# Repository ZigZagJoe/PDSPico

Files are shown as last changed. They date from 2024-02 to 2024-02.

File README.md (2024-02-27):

# PDSPico

early days of a project to interface a Pico W microcontroller to a 68030 bus
hardware has been validated, code WIP

## modes of access.

### PICO starts at 0xfX000000

16 bit port, 4 address bits A8-A11

intended for use as FIFOs between Pico and 68030 for bulk data transfer
anticipated to be accelerated by PIOs

### Status  at     0xfX400000

8 bit port, no address bits. 

automatically dsack by GAL. intent is to allow the pico to leave status flags on its bus and the 68030 can poll without needing to interrupt pico

### ROM starts at  0xfXc00000

8 bit port, 12 address bits A0-A11 (4KB)

intended to provide DeclROM emulation, but as this will also be writable it can be used for ancillary data transfer/registers
expected to be slower as pico CPU will need to be interrupted to handle these accesses.

X is slot, A or B selectable

## IO resources:

- USB-A host port connected to pico's USB port: possibility for mass storage or other fun things
- Wifi on the Pico module
- One free output on the GAL
- No free IO on the Pico. One output used for two LEDs: could be repurposed.
- The upper section of the multiplexed data bus could possibly be used for shared IO, but this would require blocking of the host's access to anything but status bits....

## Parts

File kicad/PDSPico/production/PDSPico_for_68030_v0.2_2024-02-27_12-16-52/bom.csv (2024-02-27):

Designator | Footprint | Quantity | Value | LCSC Part #
C1, C14, C15, C2, C4 | 0805 | 5 | 22uF | C45783
C3, C6, C7, C8, C9 | 0805 | 5 | 220nf | C5378
CN1 | 650949-5 RA MALE | 1 | PDS_LB_MALE | C3652939
D1 | D_SOD-323_HandSoldering | 1 | D_Schottky | C191023
D2 | 0805 | 1 | RED | C84256
D3 | 0805 | 1 | GRN | C2297
F1 | 1210 | 1 | 1.1A 6V | C2649912
J2 | USB_A_Horizontal_Generic | 1 | USB_A | C720525
JP1 | PinHeader_1x02_P2.54mm_Vertical | 1 | SLOT | N/A
R1 | 0805 | 1 | 1K | C17513
R10, R11, R12, R13, R14, R15, R16, R17, R18, R21, R22, R23, R24, R3, R4, R5, R6, R7, R8, R9 | 0805 | 20 | 200 | C17540
R19, R2, R20 | 0805 | 3 | 4.7K | C17673
TP1 | TestPoint-2 RRect 1.5mmX2mm | 1 | USB_DATA | N/A
U1, U4 | SOIC-20W_7.5x12.8mm_P1.27mm | 2 | 74LV*245 | C571201
U2 | SOT-223-3_TabPin2 | 1 | 1117-3.3 | C6186
U3 | RPi_Pico_SMD | 1 | RPI Pico W | N/A
U5 | DIP-24_W7.62mm_Socket | 1 | ATF22V10 | C146581
U6, U7 | SOIC-20W_7.5x12.8mm_P1.27mm | 2 | 74LV*541 | C2652110

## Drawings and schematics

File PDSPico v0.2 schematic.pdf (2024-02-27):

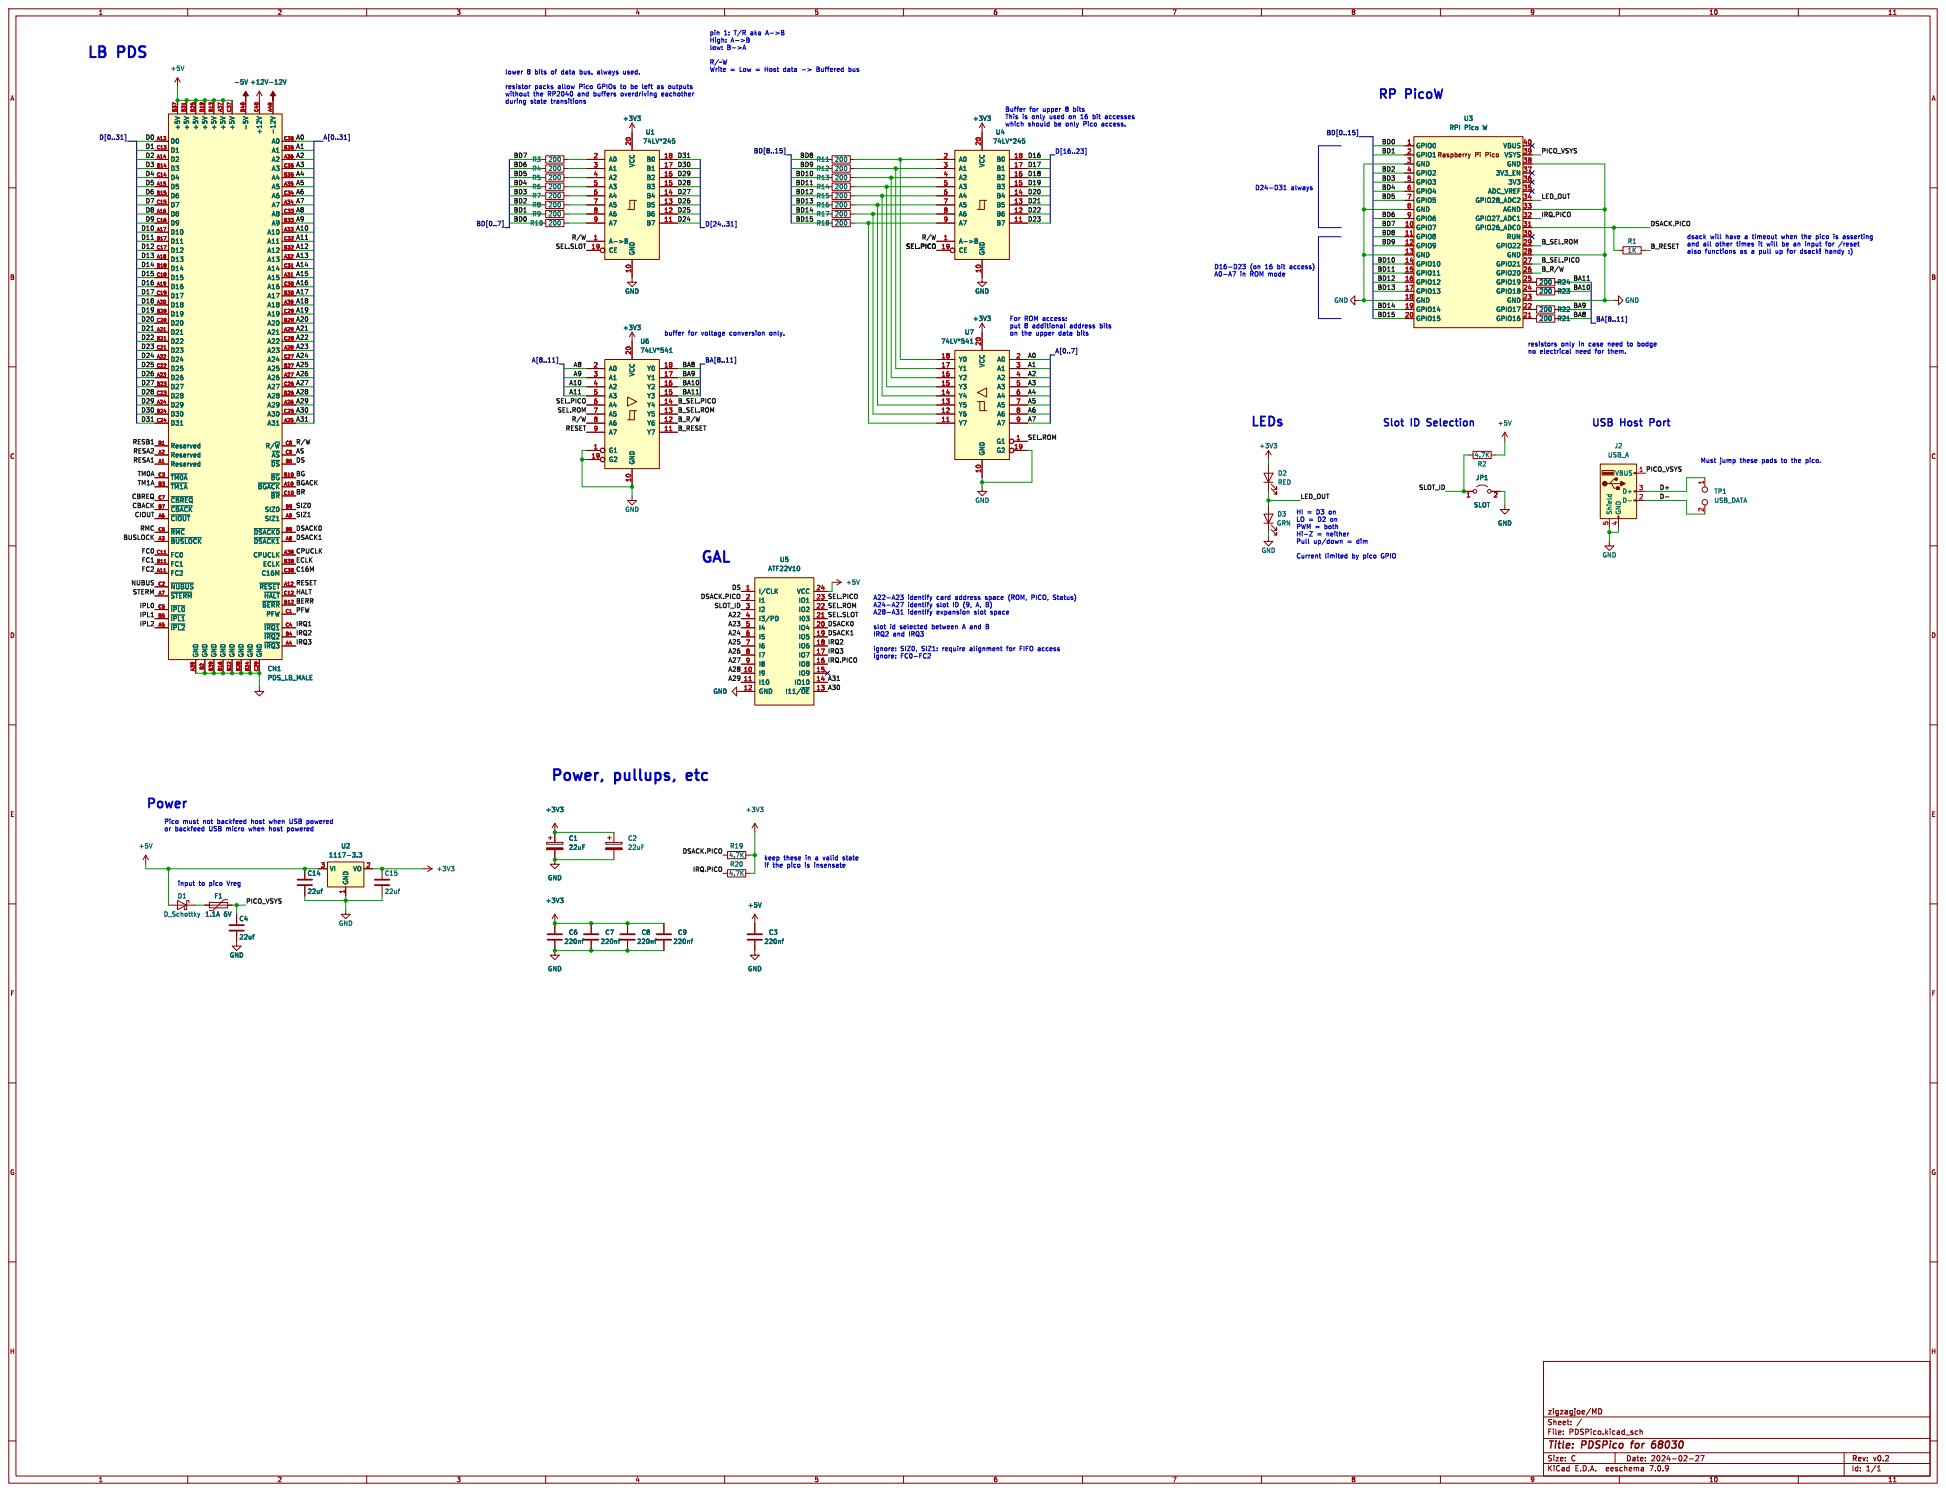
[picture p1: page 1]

Must jump these pads to the pico.

Current limited by pico GPIO

ignore: FC0-FC2 Power, pullups, etc

Pico must not backfeed host when USB powered
or backfeed USB micro when host powered

keep these in a valid state

input to pico Vreg

File: PDSPico.kicad_sch Sheet: / zigzagjoe/MD

Id: 1/1 Title: PDSPico for 68030

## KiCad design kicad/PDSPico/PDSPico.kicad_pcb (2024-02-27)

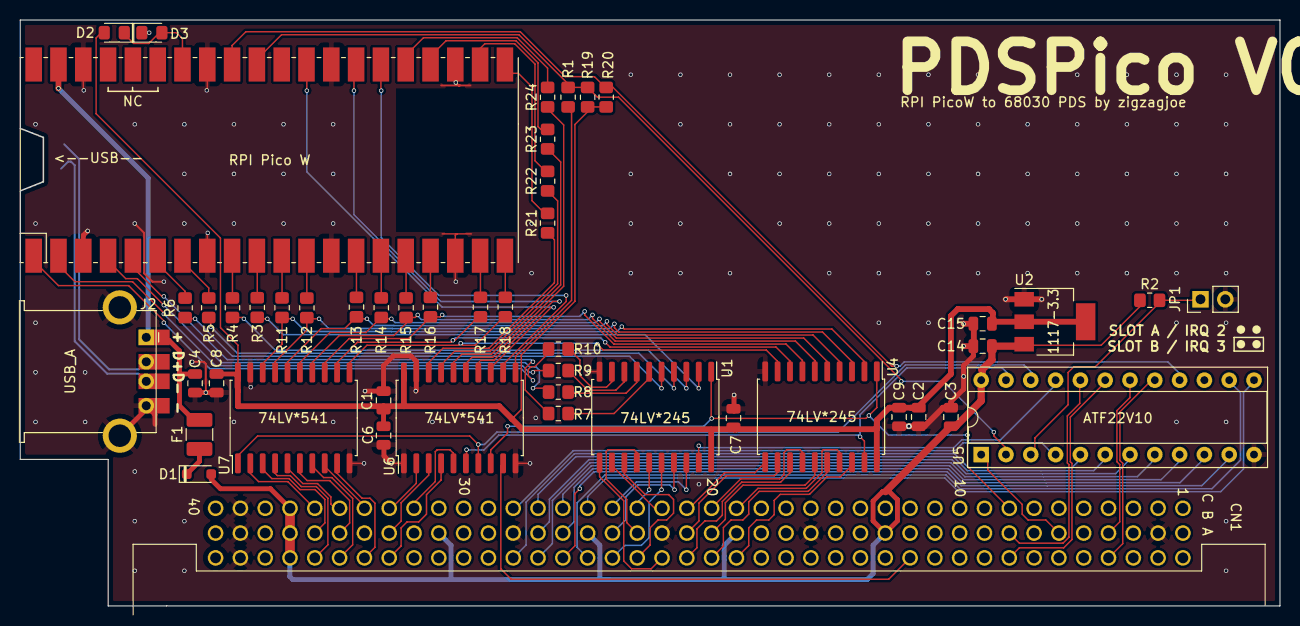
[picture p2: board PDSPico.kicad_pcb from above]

Board: 2 copper layers, 129.0 x 60.0 mm, 49 parts (1 on the bottom side), 103 nets.

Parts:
C1, C2: 22uF; C_0805_2012Metric
C3, C6, C7, C8, C9: 220nf; C_0805_2012Metric
C4, C14, C15: 22uf; C_0805_2012Metric
CN1: PDS_LB_MALE; 650949-5 RA MALE
D1: D_Schottky; D_SOD-323_HandSoldering
D2: RED; LED_0805_2012Metric_Pad1.15x1.40mm_HandSolder
D3: GRN; LED_0805_2012Metric_Pad1.15x1.40mm_HandSolder
F1: 1.1A 6V; Fuse_1210_3225Metric_Pad1.42x2.65mm_HandSolder
J2: USB_A; USB_A_Horizontal_Generic
JP1: SLOT; PinHeader_1x02_P2.54mm_Vertical
R1: 1K; R_0805_2012Metric_Pad1.20x1.40mm_HandSolder
R2, R19, R20: 4.7K; R_0805_2012Metric_Pad1.20x1.40mm_HandSolder
R3, R4, R5, R6, R7, R8, R9, R10, R11, R12, R13, R14, R15, R16, R17, R18, R21, R22, R23, R24: 200; R_0805_2012Metric_Pad1.20x1.40mm_HandSolder
TP1: USB_DATA; TestPoint-2 RRect 1.5mmX2mm
U1, U4: 74LV*245; SOIC-20W_7.5x12.8mm_P1.27mm
U2: 1117-3.3; SOT-223-3_TabPin2
U3: RPI Pico W; RPi_Pico_SMD
U5: ATF22V10; DIP-24_W7.62mm_Socket
U6, U7: 74LV*541; SOIC-20W_7.5x12.8mm_P1.27mm

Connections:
+3V3: C1.1, C2.1, C6.1, C7.1, C8.1, C9.1, C15.1, D2.2 (A), R19.2, R20.1, U1.20 (VCC), U2.2 (VO), U4.20 (VCC), U6.20 (VCC), U7.20 (VCC)
+5V: C3.1, C14.1, CN1.A37 (+5V), CN1.B13 (+5V), CN1.B19 (+5V), CN1.B25 (+5V), CN1.B31 (+5V), CN1.B37 (+5V), CN1.C37 (+5V), D1.2 (A), R2.1, U2.3 (VI), U5.24 (VCC)
/A0: CN1.C36 (A0), U7.2 (A0)
/A1: CN1.B36 (A1), U7.3 (A1)
/A2: CN1.A36 (A2), U7.4 (A2)
/A3: CN1.C35 (A3), U7.5 (A3)
/A4: CN1.B35 (A4), U7.6 (A4)
/A5: CN1.A35 (A5), U7.7 (A5)
/A6: CN1.C34 (A6), U7.8 (A6)
/A7: CN1.A34 (A7), U7.9 (A7)
/A8: CN1.C33 (A8), U6.2 (A0)
/A9: CN1.B33 (A9), U6.3 (A1)
/A10: CN1.A33 (A10), U6.4 (A2)
/A11: CN1.C32 (A11), U6.5 (A3)
/A22: CN1.C28 (A22), U5.4 (I3/PD)
/A23: CN1.A28 (A23), U5.5 (I4)
/A24: CN1.C27 (A24), U5.6 (I5)
/A25: CN1.B27 (A25), U5.7 (I6)
/A26: CN1.A27 (A26), U5.8 (I7)
/A27: CN1.C26 (A27), U5.9 (I8)
/A28: CN1.B26 (A28), U5.10 (I9)
/A29: CN1.A26 (A29), U5.11 (I10)
/A30: CN1.C25 (A30), U5.13 (I11/~OE)
/A31: CN1.A25 (A31), U5.14 (IO10)
/BA8: R21.1, U6.18 (Y0)
/BA9: R22.1, U6.17 (Y1)
/BA10: R23.1, U6.16 (Y2)
/BA11: R24.1, U6.15 (Y3)
/BD0: R10.1, U3.1 (GPIO0)
/BD1: R9.1, U3.2 (GPIO1)
/BD2: R8.1, U3.4 (GPIO2)
/BD3: R7.1, U3.5 (GPIO3)
/BD4: R6.1, U3.6 (GPIO4)
/BD5: R5.1, U3.7 (GPIO5)
/BD6: R4.1, U3.9 (GPIO6)
/BD7: R3.1, U3.10 (GPIO7)
/BD8: R11.1, U3.11 (GPIO8)
/BD9: R12.1, U3.12 (GPIO9)
/BD10: R13.1, U3.14 (GPIO10)
/BD11: R14.1, U3.15 (GPIO11)
/BD12: R15.1, U3.16 (GPIO12)
/BD13: R16.1, U3.17 (GPIO13)
/BD14: R17.1, U3.19 (GPIO14)
/BD15: R18.1, U3.20 (GPIO15)
/B_RESET: R1.2, U6.11 (Y7)
/B_R/W: U3.26 (GPIO20), U6.12 (Y6)
/B_SEL.PICO: U3.27 (GPIO21), U6.14 (Y4)
/B_SEL.ROM: U3.29 (GPIO22), U6.13 (Y5)
/D16: CN1.A19 (D16), U4.18 (B0)
/D17: CN1.C19 (D17), U4.17 (B1)
/D18: CN1.A20 (D18), U4.16 (B2)
/D19: CN1.B20 (D19), U4.15 (B3)
/D20: CN1.C20 (D20), U4.14 (B4)
/D21: CN1.A21 (D21), U4.13 (B5)
/D22: CN1.B21 (D22), U4.12 (B6)
/D23: CN1.C21 (D23), U4.11 (B7)
/D24: CN1.A22 (D24), U1.11 (B7)
/D25: CN1.C22 (D25), U1.12 (B6)
/D26: CN1.A23 (D26), U1.13 (B5)
/D27: CN1.B23 (D27), U1.14 (B4)
/D28: CN1.C23 (D28), U1.15 (B3)
/D29: CN1.A24 (D29), U1.16 (B2)
/D30: CN1.B24 (D30), U1.17 (B1)
/D31: CN1.C24 (D31), U1.18 (B0)
/D+: J2.3 (D+), TP1.1
/D-: J2.2 (D-), TP1.2
/DS: CN1.B6 (~DS), U5.1 (I/CLK)
/DSACK0: CN1.B8 (~DSACK0), U5.20 (IO4)
/DSACK1: CN1.A8 (~DSACK1), U5.19 (IO5)
/DSACK.PICO: R1.1, R19.1, U3.31 (GPIO26_ADC0), U5.2 (I1)
/IRQ2: CN1.B4 (~IRQ2), U5.18 (IO6)
/IRQ3: CN1.A4 (~IRQ3), U5.17 (IO7)
/IRQ.PICO: R20.2, U3.32 (GPIO27_ADC1), U5.16 (IO8)
/LED_OUT: D2.1 (K), D3.2 (A), U3.34 (GPIO28_ADC2)
/PICO_VSYS: C4.1, F1.2, J2.1 (VBUS), U3.39 (VSYS)
/RESET: CN1.A12 (~RESET), U6.9 (A7)
/R/W: CN1.C8 (R/~W), U1.1 (A->B), U4.1 (A->B), U6.8 (A6)
/SEL.PICO: U4.19 (CE), U5.23 (IO1), U6.6 (A4)
/SEL.ROM: U5.22 (IO2), U6.7 (A5), U7.1 (G1)
/SEL.SLOT: U1.19 (CE), U5.21 (I03)
/SLOT_ID: JP1.1 (A), R2.2, U5.3 (I2)
GND: C1.2, C2.2, C3.2, C4.2, C6.2, C7.2, C8.2, C9.2, C14.2, C15.2, CN1.A39 (GND), CN1.B2 (GND), CN1.B16 (GND), CN1.B22 (GND), CN1.B28 (GND), CN1.B34 (GND), CN1.B39 (GND), CN1.C39 (GND), D3.1 (K), J2.4 (GND), J2.5 (Shield), JP1.2 (B), U1.10 (GND), U2.1 (GND), U3.3 (GND), U3.8 (GND), U3.13 (GND), U3.18 (GND), U3.23 (GND), U3.28 (GND), U3.33 (AGND), U3.38 (GND), U4.10 (GND), U5.12 (GND), U6.1 (G1), U6.10 (GND), U6.19 (G2), U7.10 (GND), U7.19 (G2)
unnamed: D1.1 (K), F1.1
unnamed: R3.2, U1.2 (A0)
unnamed: R4.2, U1.3 (A1)
unnamed: R5.2, U1.4 (A2)
unnamed: R6.2, U1.5 (A3)
unnamed: R7.2, U1.6 (A4)
unnamed: R8.2, U1.7 (A5)
unnamed: R9.2, U1.8 (A6)
unnamed: R10.2, U1.9 (A7)
unnamed: R21.2, U3.21 (GPIO16)
unnamed: R22.2, U3.22 (GPIO17)
unnamed: R23.2, U3.24 (GPIO18)
unnamed: R24.2, U3.25 (GPIO19)
unnamed: R11.2, U4.2 (A0), U7.18 (Y0)
unnamed: R12.2, U4.3 (A1), U7.17 (Y1)
unnamed: R13.2, U4.4 (A2), U7.16 (Y2)
unnamed: R14.2, U4.5 (A3), U7.15 (Y3)
unnamed: R15.2, U4.6 (A4), U7.14 (Y4)
unnamed: R16.2, U4.7 (A5), U7.13 (Y5)
unnamed: R17.2, U4.8 (A6), U7.12 (Y6)
unnamed: R18.2, U4.9 (A7), U7.11 (Y7)

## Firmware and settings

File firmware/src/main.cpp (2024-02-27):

#include <Arduino.h>
#include <device/usbd.h>

#include "util.h"
#include "gpio.h"

void setup() {
	board_gpio_init();

	util_init();

	led_set(GREEN_DIM);
}

void setup1() {
	delay(100);
	dbg_printf("Core 1 start\n");
}

volatile struct {
	uint16_t romAddr;
	uint8_t romData;
	uint8_t fifoAddr;
	uint16_t fifoData;
	uint32_t fifoCount;
	uint32_t romCount;
	uint8_t direction;
} lastState;

	
//, 0x
uint8_t ROM_Data[4096] = { 0xDE, 0xAD, 0xBE, 0xEF, 0xBA, 0xAD, 0xF0, 0x0D, 0xFE, 0xED, 0xFA, 0xCE, 0xCA,0xFE,0xBA,0xBE };

void loop1() {

	memset((void *)&lastState,0,sizeof(lastState));
	lastState.romData = 0x79;
	lastState.fifoData = 0xADDE;

	cli();

	data_out();
	data_write(lastState.romData);

	while(1) {
		uint32_t state = gpio_get_all();
		if (!(state & bv(SEL_PICO))) {
			lastState.fifoAddr = (state & ADDR_BUS_A8_MASK) >> 16;

			if (!(state & bv(READ_WRITE))) {
				data_in();
				busy_wait_at_least_cycles(2);
				lastState.fifoData = data_read();
				lastState.direction = 0;
			} else {
				data_write(lastState.fifoData); // must swap bytes for 16 bit IO ie 0xDEAD becomes 0xADDE
				lastState.direction = 1;
			}

			gpio_put(DSACK_PICO,0);
			busy_wait_at_least_cycles(10);
			gpio_put(DSACK_PICO,1);
			
			data_out();
			data_write(lastState.romData);

			led_set(GREEN);
			lastState.fifoCount++;

		} else if (! (state & bv(SEL_ROM))) {
			gpio_set_dir_masked(ADDR_BUS_A0_MASK,0); // set BD8-15 as inputs
			busy_wait_at_least_cycles(2); // small delay required before reading address bits. 1 or more seesm to work
			lastState.romAddr = (gpio_get_all() & ADDR_BUS_A0_FULLMASK) >> 8;
				
			if (!(state & bv(READ_WRITE))) {
				data_in();
				busy_wait_at_least_cycles(2);
				lastState.romData = data_read() & 0xFF;
				ROM_Data[lastState.romAddr] = lastState.romData;
				lastState.direction = 0;
			} else {
				data_write(ROM_Data[lastState.romAddr]);
				lastState.direction = 1;
			}
			
			gpio_put(DSACK_PICO,0);
			busy_wait_at_least_cycles(10);
			gpio_put(DSACK_PICO,1);
			
			data_out();
			data_write(lastState.romData);

			led_set(RED);
			lastState.romCount++;
		}
	}
}

/* main loop. most code runs from tinyusb task rather than here. */
void loop() {

	uint32_t lfc = 0, lrc = 0;

	while(1) {
		// platformio device monitor is dumb, and will purge any pending serial lines.
		// wait a moment before starting to dump serial logs out... as I am lazy.
		if (millis() > 3000) 
			dbg_flush_log();

		// serial bridge / command interface
		//poll_serial();

		if (lrc != lastState.romCount) {
			lrc = lastState.romCount;
			dbg_printf("rom count %d\n%c ($%x) = $%x\n",lastState.romCount,lastState.direction?'R':'W',lastState.romAddr,lastState.romData);	
		}

		if (lfc != lastState.fifoCount) {
			lfc = lastState.fifoCount;
			dbg_printf("fifo count %d\n%c ($%d) = $%x\n",lastState.fifoCount,lastState.direction?'R':'W',lastState.fifoAddr,lastState.fifoData);	
		}
	}
}

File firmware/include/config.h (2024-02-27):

/* file for compile time configurable constants */
#ifndef CONFIG_H
#define CONFIG_H

#include "version.h"

#define PRODUCT_NAME                "PDSPico"
// max 8 chars, it is used as USB VID
#define PRODUCT_VENDOR              "ZZJ"
#define PRODUCT_VERSION             VERSION_SHORT

/** SERIAL PARAMETERS ********************************************/

// serial logging and logfile shared buffer
#define SERIAL_BUFF_SZ              4096

#define SERIAL_MAX_LINE_LEN         256
#define SERIAL_MAX_TIMESTAMP_LEN    20

// delay in ms after escape sequence
#define SERIAL_CMD_BACKOFF          500
#define SERIAL_DEFAULT_BAUD         9600
#define SERIAL_BAUD_MAX             1000000

/** FLASH PARAMETERS ********************************************/

#define FLASH_BANKS                 (2)

/* flash bank size in words */
#define FLASH_BANK_WORDS            (4 * 1024 * 1024)

/* flash bank size in bytes */
#define FLASH_BANK_BYTES            (FLASH_BANK_WORDS * 2)

#define FLASH_SIZE_WORDS            (FLASH_BANKS * FLASH_BANK_WORDS)
#define FLASH_SIZE_BYTES            (FLASH_BANKS * FLASH_BANK_BYTES)

// number of sectors. require uniform sector ROM (do not support boot sector ROM)
#define FLASH_SECTORS               128

// size of flash chip's write buffer
#define FLASH_BLOCKSIZE             256

// roughly map to flash cycle time (X*7.5ns at 133mhz)
#define FLASH_DELAY_CYCLES          9

/** UF2 PARAMETERS *********************************************/

#define BOARD_UF2_FAMILY_ID         0x10C68030

#define UF2_VOLUME_LABEL            PRODUCT_NAME

// flash bytes per UF2 file
#define CFG_UF2_FLASH_SIZE          FLASH_BANK_BYTES

// Number of 512-byte blocks in the exposed filesystem, 0x10109 is just under 32MB and works with CFG_UF2_SECTORS_PER_CLUSTER = 1
// The filesystem needs space for the current file, text files, uploaded file, and FAT
#define CFG_UF2_NUM_BLOCKS          (0x10109 * 2)

// Sectors per FAT cluster, must be increased proportionally for larger filesystems
#define CFG_UF2_SECTORS_PER_CLUSTER (4)

// timeout after which the current operation is aborted
#define WATCHDOG_TIMEOUT            5000

// small grace period after writes finish before ejecting USB storage
// required so host doesn't fail the copy transfer
#define MSC_RESET_TIMEOUT           1000

#endif

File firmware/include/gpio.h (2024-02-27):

#ifndef _GPIO_H_
#define _GPIO_H_

#include <hardware/gpio.h>
#include "util.h"

/* PIN DEFINITIONS *****************************************/
// data bus, 16 bits wide
#define DATA_BUS_D0		0
#define DATA_BUS_WIDTH	16
#define DATA_BUS_MASK 	0xFFFF // 16 bits

#define ADDR_BUS_A0		8
#define ADDR_BUS_A0_MASK 	    0x0FF00 // 8 bits
#define ADDR_BUS_A0_FULLMASK 	0xFFF00 // 12 bits

/* BA8-BA11 */
#define ADDR_BUS_A8		16
#define ADDR_BUS_WIDTH	4
#define ADDR_BUS_A8_MASK 	    0xF0000 // 4 bits


#define SEL_ROM		22
#define SEL_PICO		21

#define READ_WRITE		20

#define DSACK_PICO		26
#define RESET_IN		26

#define IRQ_PICO		27

/* LED output
 hi-Z = off
	1 = green
	0 = red
	pull up/down for dim colors
*/
#define LED_OUT			28

// detect vbus present
#define VBUS_SENSE		24

/* misc defines *******************************************/

/* LED states for set_led */
enum LED_STATE { GREEN, GREEN_DIM, BOTH, RED, RED_DIM, OFF };

/* prototypes *********************************************/

#ifdef __cplusplus
extern "C" {
#endif

extern enum LED_STATE last_led_state;

/* set pin to GPIO mode, with direction and initial state */
void init_gpio_pin(uint gpio, bool dir, bool state);

/* board GPIO setup */
void board_gpio_init();

/* set LED state */
void led_set(enum LED_STATE s);

/* static inline IO functions for speed */
static inline void data_out() { 
	gpio_set_dir_masked(DATA_BUS_MASK, DATA_BUS_MASK); 
}

static inline void data_in()  { 
	gpio_set_dir_masked(DATA_BUS_MASK, 0); 
}

static inline uint16_t data_read() {
	return gpio_get_all() & DATA_BUS_MASK;
}

static inline void data_write(uint16_t d) {
	gpio_put_masked(DATA_BUS_MASK,d);
}


#ifdef __cplusplus
}
#endif

#endif
